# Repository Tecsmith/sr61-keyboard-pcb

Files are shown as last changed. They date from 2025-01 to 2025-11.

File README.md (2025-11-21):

# SR61 - MicroMod 60% Custom Keyboard PCB





***Featuring SparkFun's MicroMod Processor Boards***

---

> [PCBWay](https://pcbway.com) had gratefully sponsored the production of the first 5 RevA PCBs, and a partial assembly service.
>
> Official Sponsor - PCBWay (https://pcbway.com/)
>
> Thank you [PCBWay](https://pcbway.com/)!

Please follow the updates to this production process on the [changelog](CHANGELOG.md) page.

---

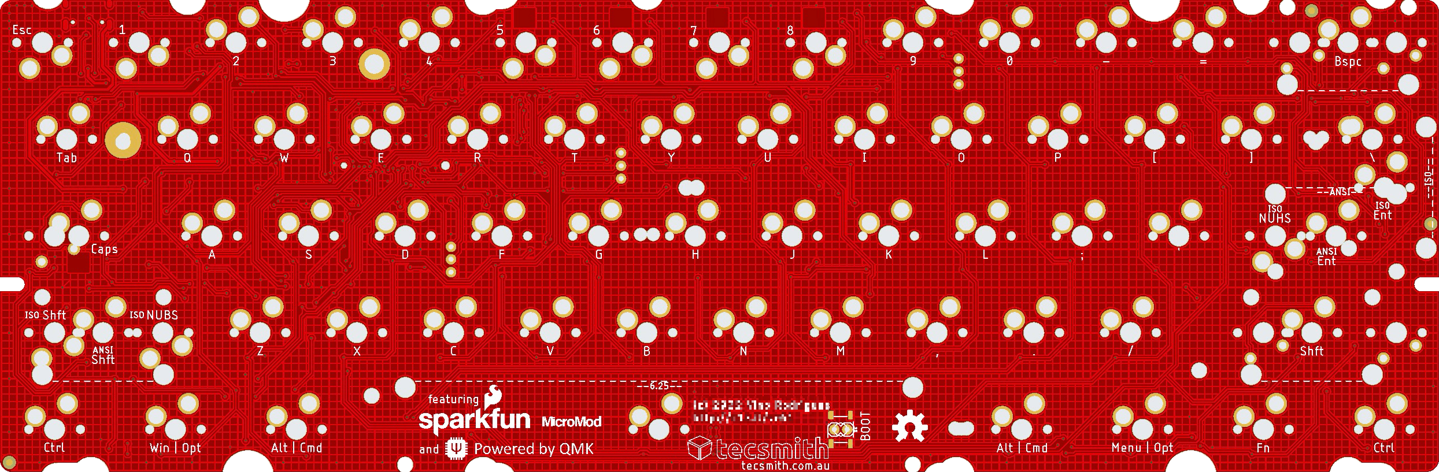
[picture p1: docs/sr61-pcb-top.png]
PCB Top View


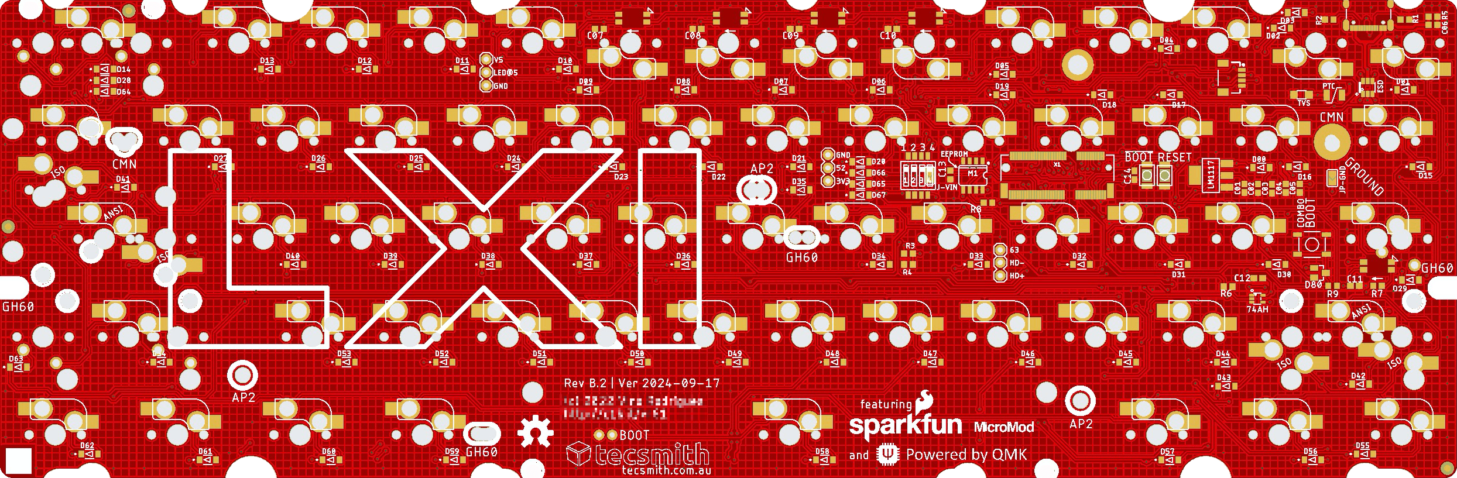
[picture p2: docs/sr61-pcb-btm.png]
PCB Bottom View


Published as Open Source, under a [ Creative Commons Share-alike 4.0 International](LICENSE.md).

### **Rev C** &nbsp; 

> ~~&#128077; **WORKING, OK TO BUILD**~~ &nbsp; 

* [PDF Schematic](docs/sr61-revC.pdf)
* [EAGLE PCB](EAGLE/sr61/sr61-revC.brd)
* [EAGLE Schematic](EAGLE/sr61/sr61-revC.sch)

* Notes:
    - Keymap Working on both STM32 and PR2040
    - *(Optional EEPROM not tested yet)*

### QMK code:

* https://github.com/Tecsmith/sr61-keyboard-qmk
* USB Identifier registered with [pid.codes](https://pid.codes/) = [`1209`/`7672`](https://pid.codes/1209/7672/)

### Layout

* [KLE JSON](./kle/sr61-micromod-poker.json)

*****

## Features

**SR61-MicroMod** - using SparkFun MicroMod STM32 or RP2040 M.2 module

### Core Design Elements

- 60% form factor
    - Design to be compatible with GH60/HK60 cases
    - Also compatible with Anne Pro 2 cases *(~~drop in~~ QMK replacement for existing AP2's or AP2 cases)* *[Removal of battery and minor case cut in the battery compartment required.]*
    - MicroMod positioned in case *"battery compartment"* space.

- QMK + VIA default f/w
    - Wired only *(no wireless)*
    - Default key-maps for Mac users

- User choice of microcontroller
    
    - [STM32 Processor](https://www.sparkfun.com/products/17713) 
        - ARM Cortex-M4, 168MHz, 1MB Flash, 192kB SRAM
        - https://github.com/Tecsmith/sr61-keyboard-qmk

    - [RP2040 Processor](https://www.sparkfun.com/products/17720) 
        - ARM Cortex-M0+, 133MHz, 128Mb Flash (16MB external), 264kB SRAM in six banks
        
- USB-C *(left side)*

    ... but also optional JST connector for [ai03 Unified C3 Daughterboard](https://github.com/ai03-2725/Unified-Daughterboard)

- ESD, Over Voltage and Over Current protection

    ... and cable shield noise filter

- Hot-swap, 5 pin switch slots

- PCB mounted stabs compatibility

- Dual ANSI / ISO layout support

- 61-Key (ANSI) / 62-Key (ISO) Layout [1.25, 1.25, 1.25, **6.25**, 1.25, 1.25, 1.25, 1.25] bottom row *(a.k.a. "Poker" / "POK3R" Layout)*

- Limited RGB LEDs *(SK6812 mini-E)*

    - RGB Caps Lock Indicator

    - North facing RGB's under the `5`, `6`, `7` & `8` keys for layer indicator

    - WS2812/SK6812 breakout for optional external LEDs

- Spare GPIO pins (`52` & `63`) breakout for expansion

   ... e.g., ~~add speaker~~

- Both `[Reset]` and `[Boot]` buttons *(as per MicroMod ref. design)*

    ... plus under space-bar Boot pins for bootload without disassembly *(press while inserting cable for bootloader function)*

---

Made with :heart: by Silvino R.

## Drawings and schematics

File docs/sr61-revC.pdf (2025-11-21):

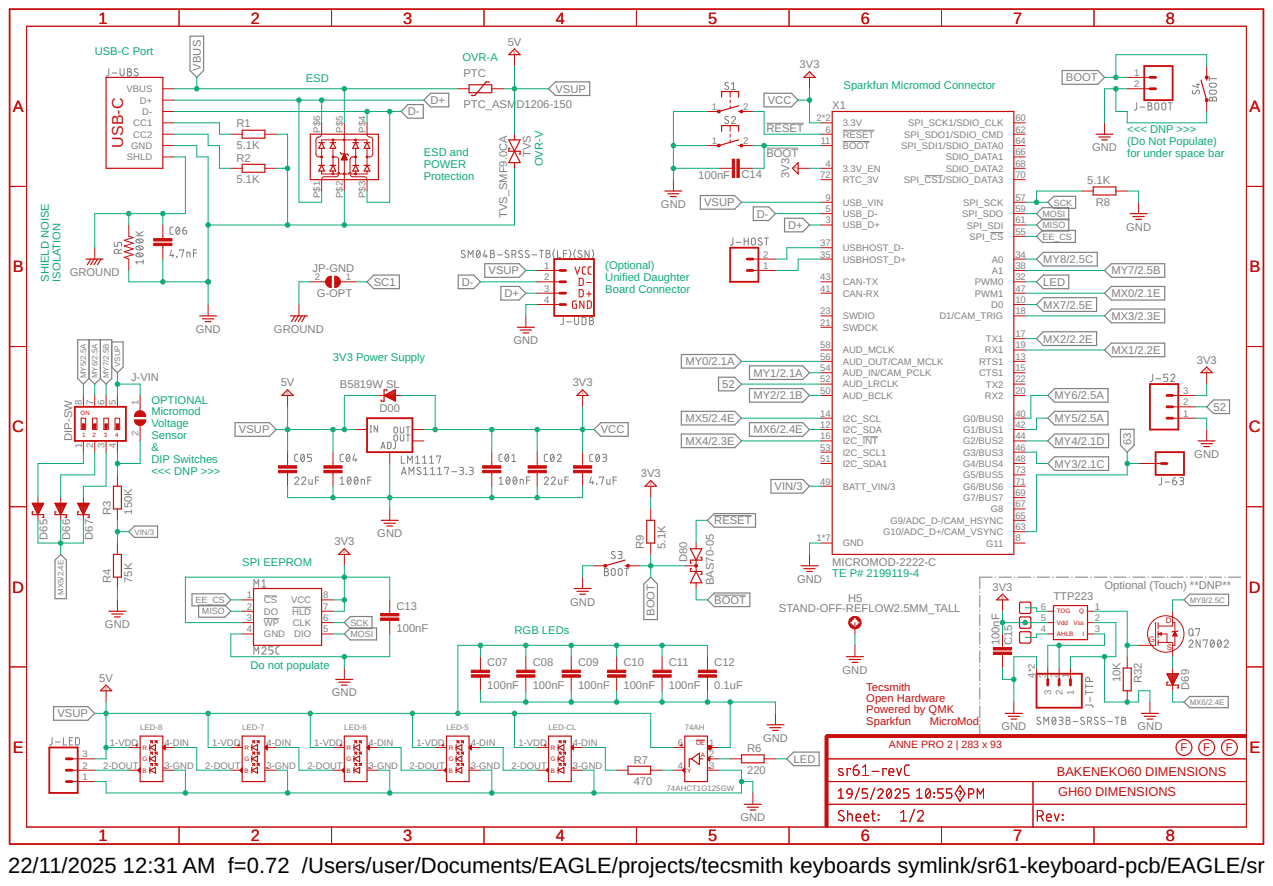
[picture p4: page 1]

<<< DNP >>>
(Do Not Populate)
GND
for under space bar

(Optional) Unified Daughter Board Connector

2 1 J-VIN
OPTIONAL Micromod Voltage Sensor &DIP Switches <<< DNP >>>

Open Hardware Sparkfun Powered by QMK

22/11/2025 12:31 AM f=0.72 /Users/user/Documents/EAGLE/projects/tecsmith keyboards symlink/sr61-keyboard-pcb/EAGLE/sr61/sr61-revC.sch (Sheet: 1/2)

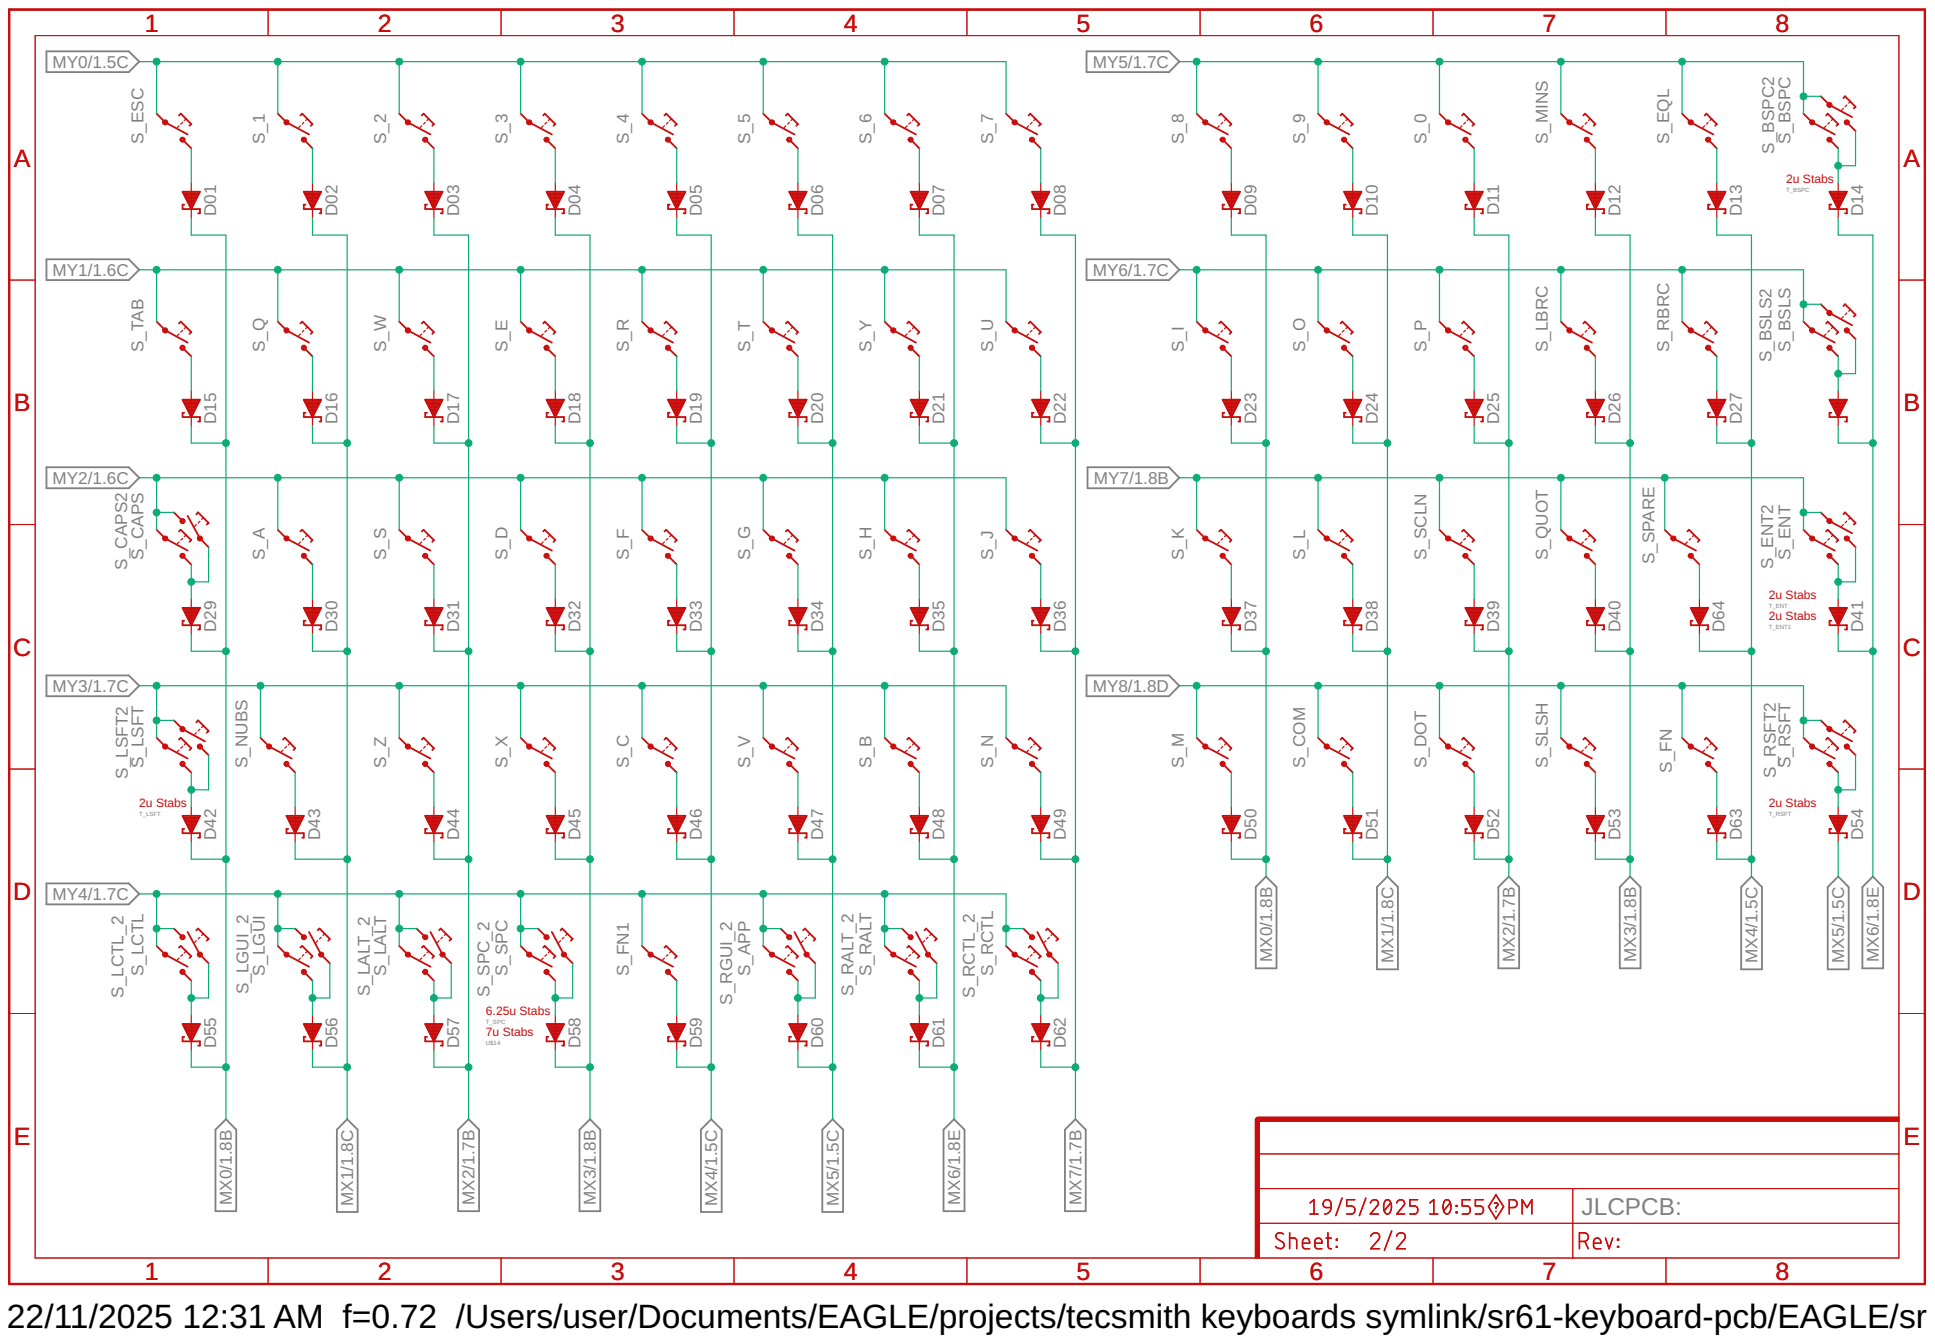
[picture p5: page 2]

22/11/2025 12:31 AM f=0.72 /Users/user/Documents/EAGLE/projects/tecsmith keyboards symlink/sr61-keyboard-pcb/EAGLE/sr61/sr61-revC.sch (Sheet: 2/2)

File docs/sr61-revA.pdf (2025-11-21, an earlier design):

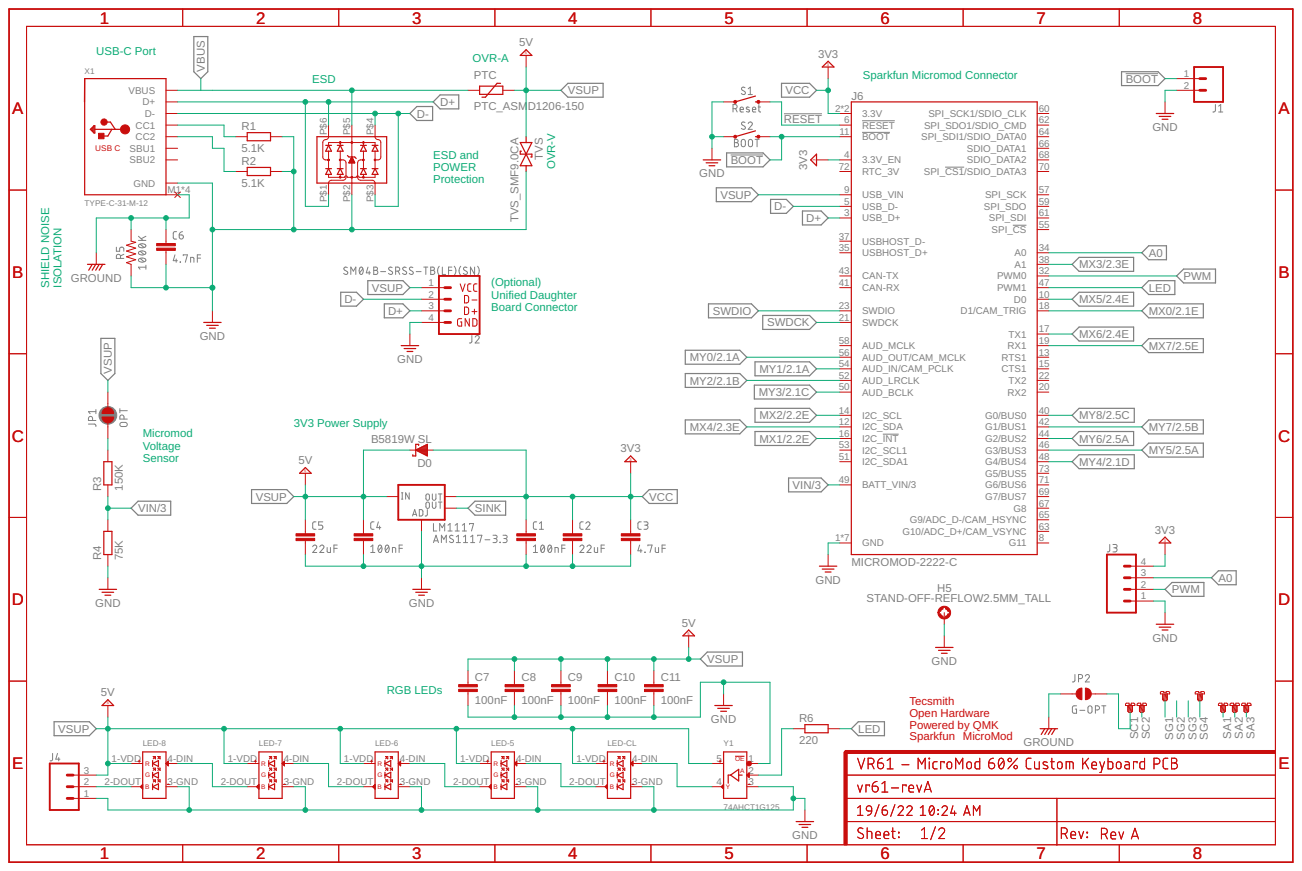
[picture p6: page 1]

(Optional)
Unified Daughter Board Connector

MX1/2.2E | I2C_SCL1 I2C_SDA1 BATT_VIN/3 | MY6/2.5A

Tecsmith
Open Hardware Sparkfun Powered by QMK

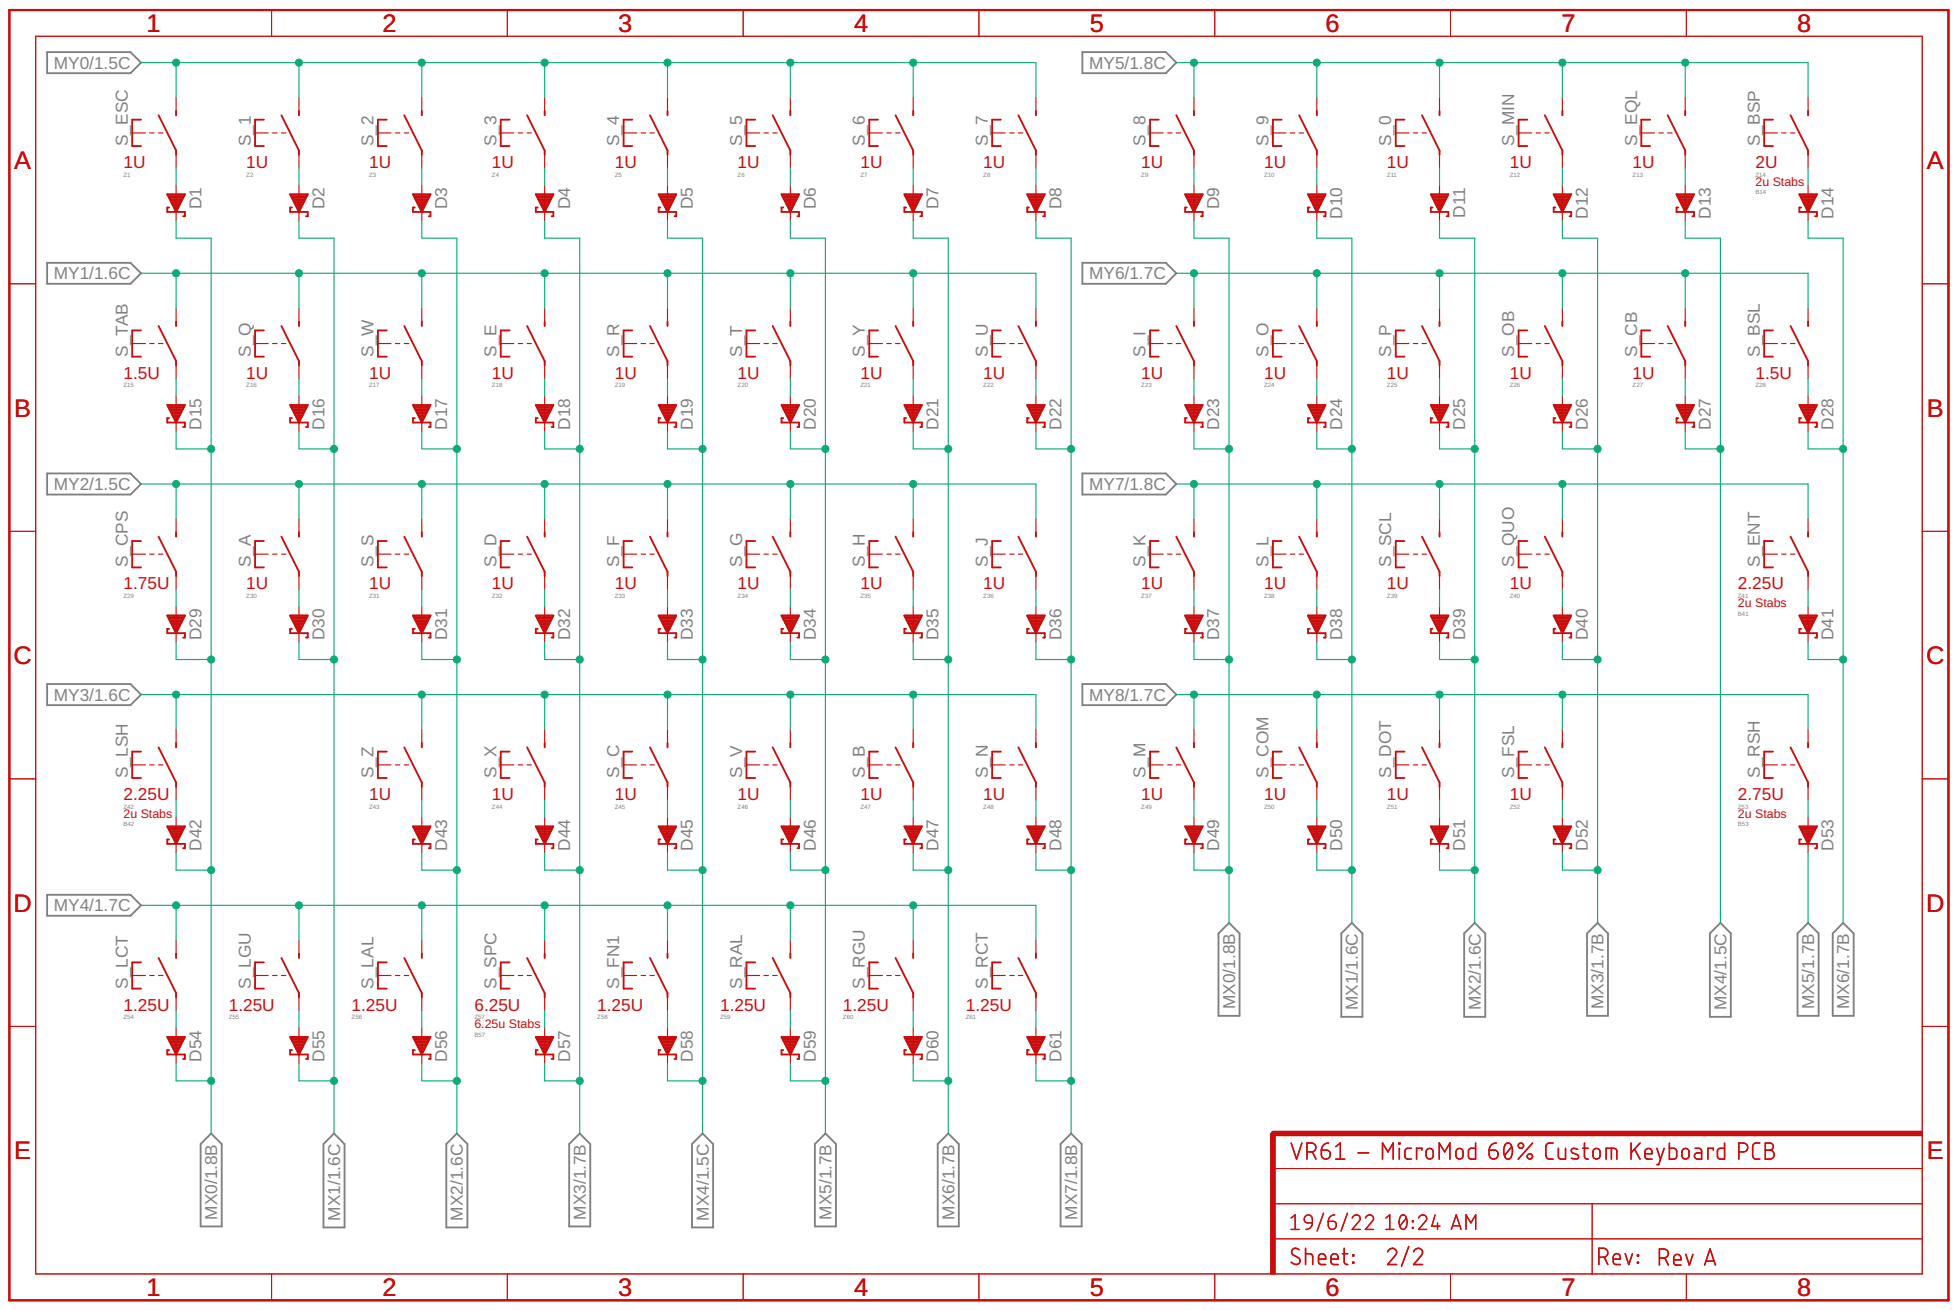
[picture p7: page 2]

S_ESC S_1 S_2 S_3 S_4 S_5 S_6 S_7 S_8 S_9 S_0 S_MIN S_EQL S_BSP D1 D2 D3 D4 D5 D6 D7 D8 D9 D10 D11 D12 D13 D14 S_TAB S_Q S_W S_E S_R S_T S_Y S_U S_I S_O S_P S_OB S_CB S_BSL D15 D16 D17 D18 D19 D20 D21 D22 D23 D24 D25 D26 D27 D28 S_CPS S_A S_S S_D S_F S_G S_H S_J S_K S_L S_SCL S_QUO S_ENT D29 D30 D31 D32 D33 D34 D35 D36 D37 D38 D39 D40 D41 S_LSH S_Z S_X S_C S_V S_B S_N S_M S_COM S_DOT S_FSL S_RSH D42 D43 D44 D45 D46 D47 D48 D49 D50 D51 D52 D53 S_LCT S_LGU S_LAL S_SPC S_FN1 S_RAL S_RGU S_RCT D54 D55 D56 D57 D58 D59 D60 D61 Z1 Z2 Z3 Z4 Z5 Z6 Z7 Z8 Z9 Z10 Z11 Z12 Z13 Z14 Z15 Z16 Z17 Z18 Z19 Z20 Z21 Z22 Z23 Z24 Z25 Z26 Z27 Z28 Z29 Z30 Z31 Z32 Z33 Z34 Z35 Z36 Z37 Z38 Z39 Z40 Z41 Z42 Z43 Z44 Z45 Z46 Z47 Z48 Z49 Z50 Z51 Z52 Z53 Z54 Z55 Z56 Z57 Z58 Z59 Z60 Z61 B14 B41 B42 B53 B57 MY0/1.5C MY1/1.6C MY2/1.5C MY3/1.6C MY4/1.7C MY5/1.8C MY6/1.7C MY7/1.8C MY8/1.7C MX5/1.7B MX5/1.7B MX6/1.7B MX6/1.7B MX7/1.8B MX0/1.8B MX0/1.8B MX1/1.6C MX1/1.6C MX2/1.6C MX2/1.6C MX3/1.7B MX3/1.7B MX4/1.5C MX4/1.5C ABCDE 1 2 3 4 5 6 7 8 ABCDE 1 2 3 4 5 6 7 8 ABCDE 1 2 3 4 5 6 7 8 ABCDE 1 2 3 4 5 6 7 8 1U 1U 1U 1U 1U 1U 1U 1U 1U 1U 1U 1U 1U 2U 1.5U 1U 1U 1U 1U 1U 1U 1U 1U 1U 1U 1U 1U 1.5U 1.75U 1U 1U 1U 1U 1U 1U 1U 1U 1U 1U 1U 2.25U 2.25U 1U 1U 1U 1U 1U 1U 1U 1U 1U 1U 2.75U 1.25U 1.25U 1.25U 6.25U 1.25U 1.25U 1.25U 1.25U 2u Stabs 2u Stabs 2u Stabs 2u Stabs 6.25u Stabs

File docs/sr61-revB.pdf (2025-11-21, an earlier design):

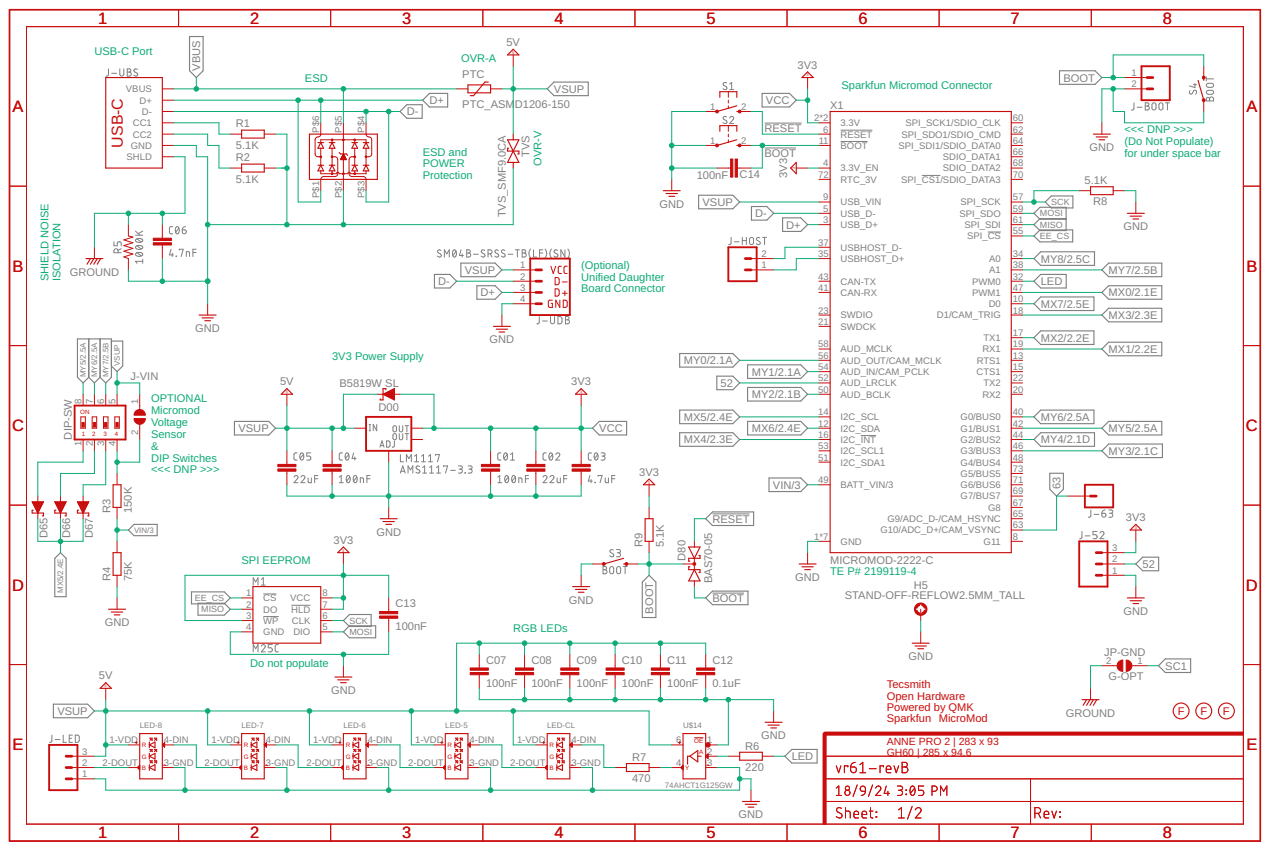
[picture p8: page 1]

<<< DNP >>>
(Do Not Populate)
GND
for under space bar

(Optional)
Unified Daughter Board Connector

Tecsmith
Open Hardware Sparkfun Powered by QMK

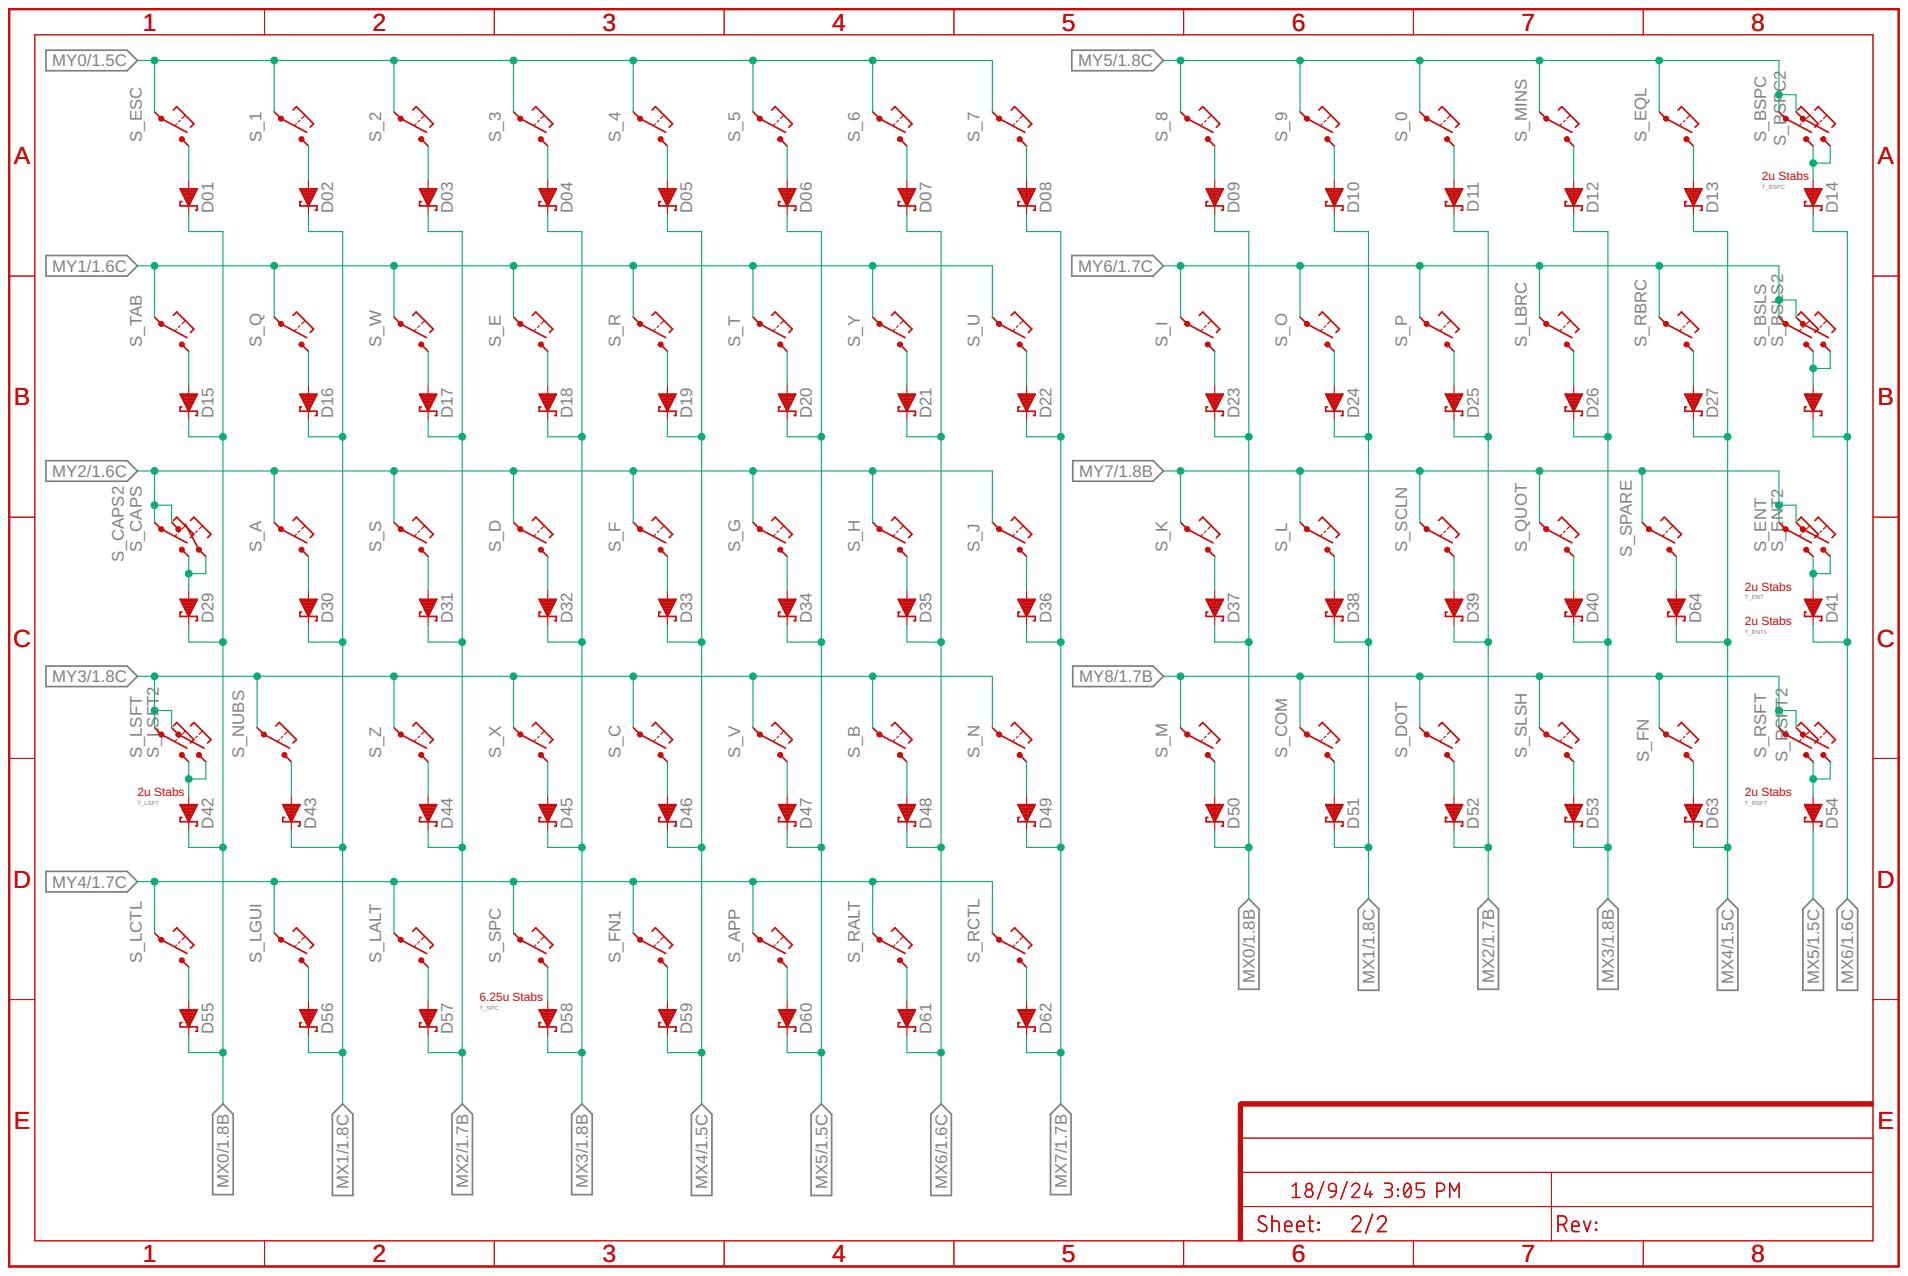
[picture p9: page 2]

S_ESC S_1 S_2 S_3 S_4 S_5 S_6 S_7 S_8 S_9 S_0 S_MINS S_EQL S_BSPC D01 D02 D03 D04 D05 D06 D07 D08 D09 D10 D11 D12 D13 D14 S_TAB S_Q S_W S_E S_R S_T S_Y S_U S_I S_O S_P S_LBRC S_RBRC S_BSLS D15 D16 D17 D18 D19 D20 D21 D22 D23 D24 D25 D26 D27 S_CAPS S_A S_S S_D S_F S_G S_H S_J S_K S_L S_SCLN S_QUOT S_ENT D29 D30 D31 D32 D33 D34 D35 D36 D37 D38 D39 D40 D41 S_LSFT S_Z S_X S_C S_V S_B S_N S_M S_COM S_DOT S_SLSH S_RSFT D42 D44 D45 D46 D47 D48 D49 D50 D51 D52 D53 D54 S_LCTL S_LGUI S_LALT S_SPC S_FN1 S_APP S_RALT S_RCTL D55 D56 D57 D58 D59 D60 D61 D62 T_BSPC T_ENT T_LSFT T_RSFT T_SPC D43 S_NUBS S_LSFT2 S_ENT2 S_BSLS2 T_ENT1 D63 S_RSFT2 S_FN S_BSPC2 S_SPARE D64 S_CAPS2 MY0/1.5C MY1/1.6C MY2/1.6C MY3/1.8C MY4/1.7C MY5/1.8C MY6/1.7C MY7/1.8B MY8/1.7B MX5/1.5C MX5/1.5C MX6/1.6C MX6/1.6C MX7/1.7B MX0/1.8B MX0/1.8B MX1/1.8C MX1/1.8C MX2/1.7B MX2/1.7B MX3/1.8B MX3/1.8B MX4/1.5C MX4/1.5C ABCDE 1 2 3 4 5 6 7 8 ABCDE 1 2 3 4 5 6 7 8 ABCDE 1 2 3 4 5 6 7 8 ABCDE 1 2 3 4 5 6 7 82u Stabs 2u Stabs 2u Stabs 2u Stabs 6.25u Stabs 2u Stabs

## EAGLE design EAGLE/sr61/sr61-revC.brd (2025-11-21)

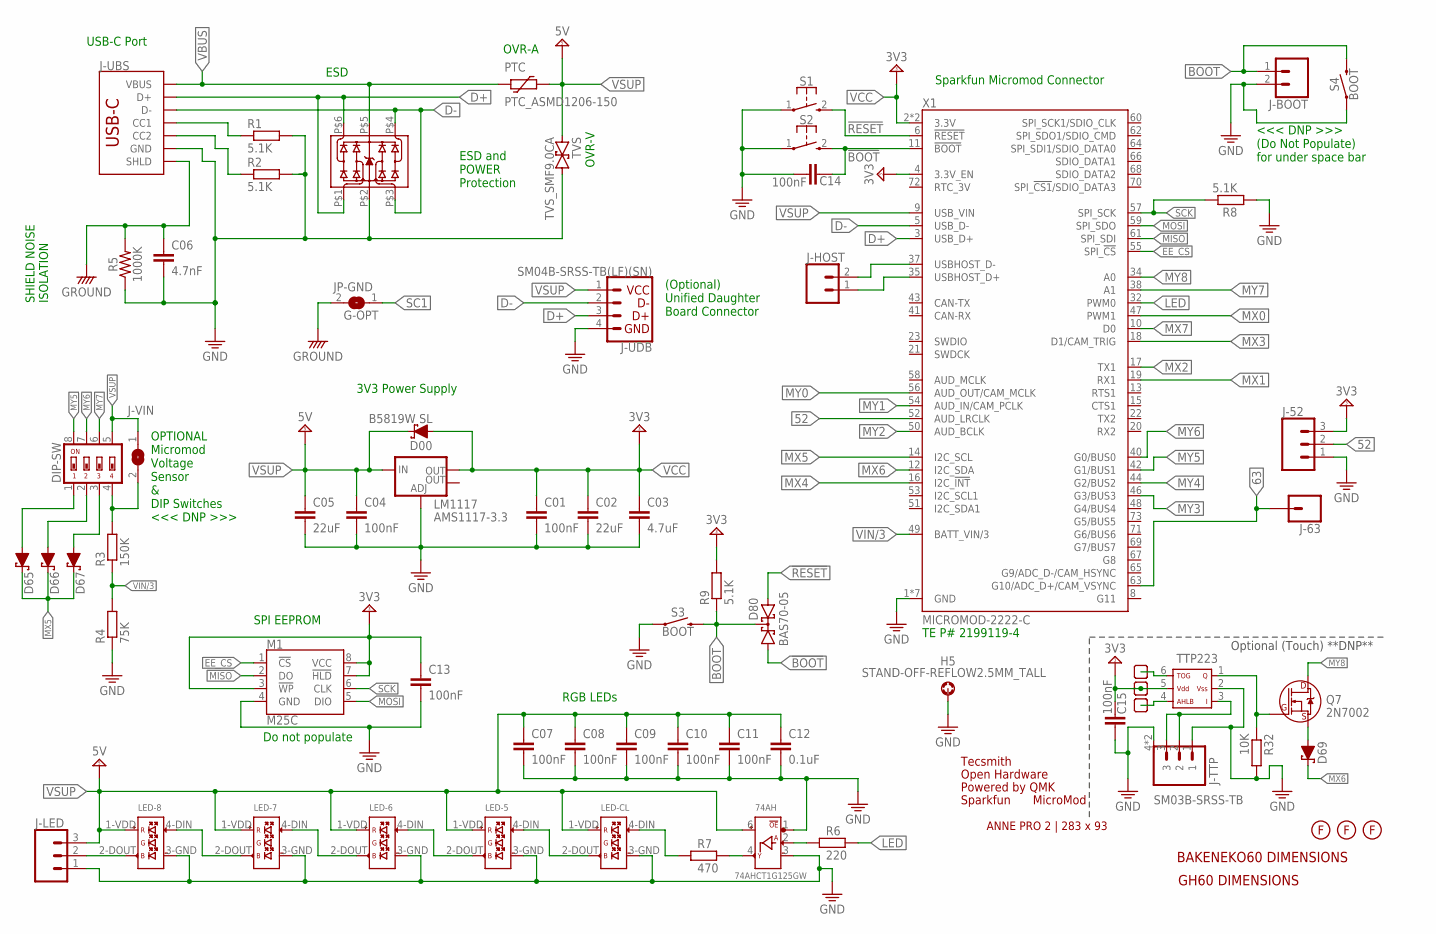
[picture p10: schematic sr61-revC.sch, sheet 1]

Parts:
74AH: 74AHCT1G125GW; SC-88A__TSSOP5__SOT353-1
C01, C04: 100nF; 0603
C02, C05: 22uF; 0603
C03: 4.7uF; 0603
C06: 4.7nF; 0603
C07, C08, C09, C10, C11, C13, C14, C15: 100nF; C0603
C12: 0.1uF; C0603
D00: B5819W SL; SOD-123
D65, D66, D67, D69: 1N5819WS; SOD-123
D80: BAS70-05; SOT23
DIP-SW: DIP004; DIP-1.27-004
ESD: ESD_SRV05-4; SOT-23-6L
FP_AP2: FOOTPRINT-AP2
H5: STAND-OFF-REFLOW2.5MM_TALL; STAND-OFF-REFLOW-M2.5
J-52: CONN_03; 1X03
J-63: CONN_01; 1X01
J-BOOT: CONN_02; 1X02
J-HOST: CONN_02; 1X02
J-LED: CONN_03; 1X03
J-TTP: SM03B-SRSS-TB; CONN_SM03B-SRSS-TB_JST
J-UBS: USB_C_2-LAYER; USB-C-16P
J-UDB: SM04B-SRSS-TB(LF)(SN); 1X04_1MM_RA
J-VIN: JUMPER-1X2; SOLDERJUMPER_ARROW_NOPASTE
JP-GND: G-OPT; SOLDERJUMPER_ARROW_NOPASTE
LED-5, LED-6, LED-7, LED-8: SK6812-E-REVERSE; SK6812-E-MILL
LED-CL: SK6812-E-REVERSE; SK6812-E-MILL
LM1117: AMS1117-3.3; SOT223
LOGO1: OSHW-LOGOL; OSHW-LOGO-L
M1: M25C; 8-SOIC
PTC: PTC_ASMD1206-150; SMD_PTC
Q7: 2N7002; SOT23-3
R1, R2, R8, R9: 5.1K; R0603
R3: 150K; R0603
R4: 75K; R0603
R5: 1000K; 0603
R6: 220; R0603
R7: 470; R0603
R32: 10K; R0603
S1, S2: MOMENTARY-SWITCH-SPST-1; SKRKAEE020
S3, S4: BOOT; TACTILE_SWITCH_SMD_5.2MM
TP1, TP2, TP3: TEST-POINT.3SQ; PAD.03X.03-SQ
TTP223: TTP223-BA6; TTP223B
TVS: TVS_SMF9.0CA; SOD123FL-BI
U$3: MICROMOD-LOGO
U$5: SPARKFUN_LOGO0.2; SFE_LOGO_NAME_FLAME_.2
U$6: QMK_LOGO
U$8: TECSMITH-LOGOLONG; TECSMITH-NAME
U$20, U$21, U$22: FIDUCIAL
U$24: FOOTPRINT-BAKENEKO60
U$27: FOOTPRINT-DIMS-GH60
X1: MICROMOD-2222-C; M.2-CONNECTOR-E

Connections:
52: J-52.2, X1.52 (AUD_LRCLK)
63: J-63.1, X1.63 (G10/ADC_D+/CAM_VSYNC)
!BOOT: C14.1, D80.1 (A1), S2.2 (3), X1.11 (!BOOT!)
!RESET: D80.2 (A2), S1.2 (3), X1.6 (!RESET!)
BOOT: D80.3 (C), J-BOOT.1, R9.1, S3.3 (2), S3.4 (2), S4.3 (2), S4.4 (2)
CC1: J-UBS.A5 (CC1), R1.1
CC2: J-UBS.B5 (CC2), R2.1
D+: ESD.P$1, ESD.P$6, J-UBS.A6 (D+), J-UBS.B6 (D+), J-UDB.3 (D+), X1.3 (USB_D+)
D-: ESD.P$3, ESD.P$4, J-UBS.A7 (D-), J-UBS.B7 (D-), J-UDB.2 (D-), X1.5 (USB_D-)
EE_CS: M1.1 (!CS), X1.55 (SPI_!CS!)
GND: 74AH.1 (!OE), 74AH.3 (3_GND), C01.2, C02.2, C03.2, C04.2, C05.2, C06.2, C07.2, C08.2, C09.2, C10.2, C11.2, C12.2, C13.2, C14.2, C15.2, ESD.P$2, H5.1, J-52.1, J-BOOT.2, J-LED.1, J-TTP.1, J-TTP.4 (M), J-TTP.5 (M), J-UBS.GND, J-UBS.GND2 (GND), J-UDB.4 (GND), LED-5.3-GND (3_GND), LED-6.3-GND (3_GND), LED-7.3-GND (3_GND), LED-8.3-GND (3_GND), LED-CL.3-GND (3_GND), LM1117.1 (ADJ), M1.4 (GND), R1.2, R2.2, R4.1, R5.1, R8.1, R32.2, S1.1, S2.1, S3.1, S3.2 (1), S4.1, S4.2 (1), TTP223.2, TVS.P$2 (2), X1.1 (GND), X1.7 (GND), X1.33 (GND), X1.36 (GND), X1.39 (GND), X1.45 (GND), X1.75 (GND)
GROUND: C06.1, J-UBS.SHLD1 (SHLD), J-UBS.SHLD2 (SHLD), J-UBS.SHLD3 (SHLD), J-UBS.SHLD4 (SHLD), J-UBS.SHLD5 (SHLD), J-UBS.SHLD6 (SHLD), J-UBS.SHLD7 (SHLD), J-UBS.SHLD8 (SHLD), JP-GND.2, R5.2
LED: R6.2, X1.32 (PWM0)
LED1ST: 74AH.2 (A_DIN), R6.1
MISO: M1.2 (DO), X1.61 (SPI_SDI)
MOSI: M1.5 (DIO), X1.59 (SPI_SDO)
MX0: X1.47 (PWM1); also elsewhere on the board
MX1: X1.19 (RX1); also elsewhere on the board
MX2: X1.17 (TX1); also elsewhere on the board
MX3: X1.18 (D1/CAM_TRIG); also elsewhere on the board
MX4: X1.16 (I2C_!INT!); also elsewhere on the board
MX5: D65.C, D66.C, D67.C, X1.14 (I2C_SCL); also elsewhere on the board
MX6: D69.C, X1.12 (I2C_SDA); also elsewhere on the board
MX7: X1.10 (D0); also elsewhere on the board
MY0: X1.56 (AUD_OUT/CAM_MCLK); also elsewhere on the board
MY1: X1.54 (AUD_IN/CAM_PCLK); also elsewhere on the board
MY2: X1.50 (AUD_BCLK); also elsewhere on the board
MY3: X1.46 (G3/BUS3); also elsewhere on the board
MY4: X1.44 (G2/BUS2); also elsewhere on the board
MY5: DIP-SW.8, X1.42 (G1/BUS1); also elsewhere on the board
MY6: DIP-SW.7, X1.40 (G0/BUS0); also elsewhere on the board
MY7: DIP-SW.6, X1.38 (A1); also elsewhere on the board
MY8: Q7.3 (D), X1.34 (A0); also elsewhere on the board
unnamed: LED-5.4-DIN (4_DIN), LED-CL.2-DOUT (2_DOUT)
unnamed: LED-5.2-DOUT (2_DOUT), LED-6.4-DIN (4_DIN)
unnamed: LED-6.2-DOUT (2_DOUT), LED-7.4-DIN (4_DIN)
unnamed: LED-7.2-DOUT (2_DOUT), LED-8.4-DIN (4_DIN)
unnamed: 74AH.4 (Y_DOUT), R7.2
unnamed: LED-CL.4-DIN (4_DIN), R7.1
unnamed: TP1.1, TTP223.6
unnamed: J-LED.2, LED-8.2-DOUT (2_DOUT)
unnamed: D65.A, DIP-SW.1
unnamed: DIP-SW.4, J-VIN.2, R3.2
unnamed: D66.A, DIP-SW.2
unnamed: D67.A, DIP-SW.3
unnamed: TP3.1, TTP223.4
unnamed: D69.A, Q7.2 (S)
unnamed: Q7.1 (G), R32.1, TTP223.1
unnamed: J-TTP.2, J-TTP.3, TTP223.3
SC1: JP-GND.1
SCK: M1.6 (CLK), R8.2, X1.57 (SPI_SCK)
USBHOST_D+: J-HOST.1, X1.35 (USBHOST_D+)
USBHOST_D-: J-HOST.2, X1.37 (USBHOST_D-)
VBUS: ESD.P$5, J-UBS.VBUS1 (VBUS), J-UBS.VBUS2 (VBUS), PTC.P$1 (1)
VCC: C01.1, C02.1, C03.1, C13.1, C15.1, D00.A, J-52.3, LM1117.2 (OUT), M1.3 (!WP), M1.7 (!HLD), M1.8 (VCC), R9.2, TP2.1, TTP223.5, X1.2 (3.3V), X1.4 (3.3V_EN), X1.74 (3.3V)
VIN/3: R3.1, R4.2, X1.49 (BATT_VIN/3)
VSUP: 74AH.6 (5_VCC), C04.1, C05.1, C07.1, C08.1, C09.1, C10.1, C11.1, C12.1, D00.C, DIP-SW.5, J-LED.3, J-UDB.1 (VCC), J-VIN.1, LED-5.1-VDD (1_VDD), LED-6.1-VDD (1_VDD), LED-7.1-VDD (1_VDD), LED-8.1-VDD (1_VDD), LED-CL.1-VDD (1_VDD), LM1117.3 (IN), PTC.P$2 (2), TVS.P$1 (1), X1.9 (USB_VIN)

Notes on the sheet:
ESD
OVR-A
OVR-V
USB-C Port
ESD and POWER Protection
OPTIONAL Micromod Voltage Sensor & DIP Switches <<< DNP >>>
(Optional) Unified Daughter Board Connector
Sparkfun Micromod Connector
3V3 Power Supply
RGB LEDs
SHIELD NOISE ISOLATION
SPI EEPROM
TE P# 2199119-4
<<< DNP >>> (Do Not Populate) for under space bar
Do not populate
Optional (Touch) **DNP**

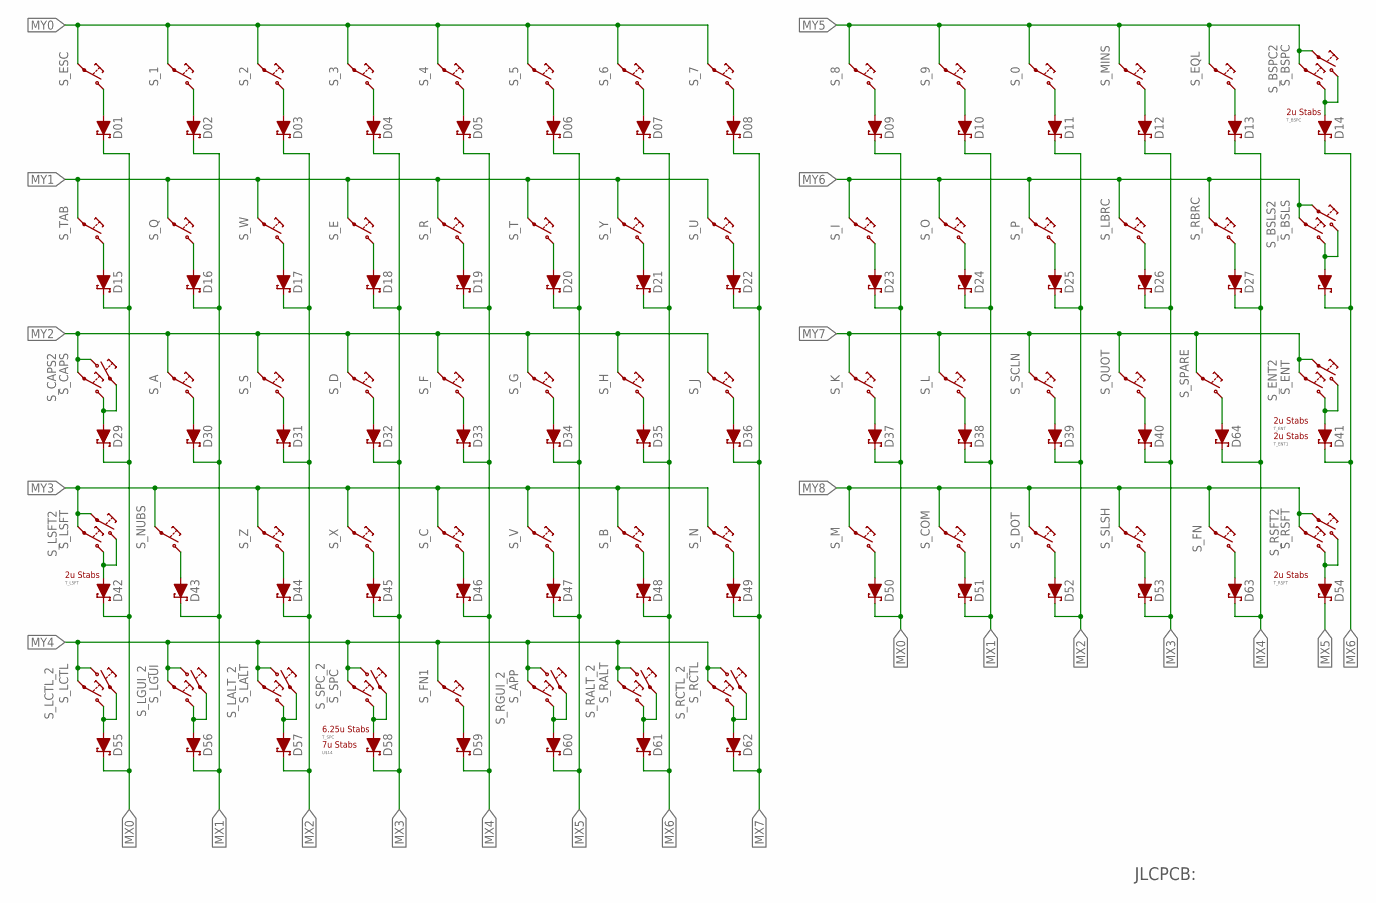
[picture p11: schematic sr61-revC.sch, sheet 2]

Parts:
D01, D02, D03, D04, D05, D06, D07, D08, D09, D10, D11, D12, D13, D14, D15, D16, D17, D18, D19, D20, D21, D22, D23, D24, D25, D26, D27, D28, D29, D30, D31, D32, D33, D34, D35, D36, D37, D38, D39, D40, D41, D42, D43, D44, D45, D46, D47, D48, D49, D50, D51, D52, D53, D54, D55, D56, D57, D58, D59, D60, D61, D62, D63, D64: 1N5819WS; SOD-123
S_0, S_1, S_2, S_3, S_4, S_5, S_6, S_7, S_8, S_9: MX-5-PIN-HOTSWAP-VIA
S_A: MX-5-PIN-HOTSWAP-VIA
S_APP: MX-5-PIN-HOTSWAP-VIA
S_B: MX-5-PIN-HOTSWAP-VIA
S_BSLS: MX-5-PIN-HOTSWAP-VIA
S_BSLS2: MX-5-PIN-HOTSWAP-VIANO-SILK; MX-5-PIN-HOTSWAP-VIA-NS
S_BSPC: MX-5-PIN-HOTSWAP-VIA
S_BSPC2: MX-5-PIN-HOTSWAP-VIANO-SILK; MX-5-PIN-HOTSWAP-VIA-NS
S_C: MX-5-PIN-HOTSWAP-VIA
S_CAPS: MX-5-PIN-HOTSWAP-VIA
S_CAPS2: MX-5-PIN-MILMAX-3305-XNO-SILK; MX-5-PIN-MILMAX-3305-X-NS
S_COM: MX-5-PIN-HOTSWAP-VIA
S_D: MX-5-PIN-HOTSWAP-VIA
S_DOT: MX-5-PIN-HOTSWAP-VIA
S_E: MX-5-PIN-HOTSWAP-VIA
S_ENT: MX-5-PIN-HOTSWAP-VIA
S_ENT2: MX-5-PIN-HOTSWAP-VIANO-SILK; MX-5-PIN-HOTSWAP-VIA-NS
S_EQL: MX-5-PIN-HOTSWAP-VIA
S_ESC: MX-5-PIN-HOTSWAP-VIA
S_F: MX-5-PIN-HOTSWAP-VIA
S_FN: MX-5-PIN-HOTSWAP-VIANO-SILK; MX-5-PIN-HOTSWAP-VIA-NS
S_FN1: MX-5-PIN-HOTSWAP-VIA
S_G: MX-5-PIN-HOTSWAP-VIA
S_H: MX-5-PIN-HOTSWAP-VIA
S_I: MX-5-PIN-HOTSWAP-VIA
S_J: MX-5-PIN-HOTSWAP-VIA
S_K: MX-5-PIN-HOTSWAP-VIA
S_L: MX-5-PIN-HOTSWAP-VIA
S_LALT: MX-5-PIN-HOTSWAP-VIA
S_LALT_2: MX-5-PIN-HOTSWAP-VIANO-SILK; MX-5-PIN-HOTSWAP-VIA-NS
S_LBRC: MX-5-PIN-HOTSWAP-VIA
S_LCTL: MX-5-PIN-HOTSWAP-VIA
S_LCTL_2: MX-5-PIN-HOTSWAP-VIANO-SILK; MX-5-PIN-HOTSWAP-VIA-NS
S_LGUI: MX-5-PIN-HOTSWAP-VIA
S_LGUI_2: MX-5-PIN-HOTSWAP-VIANO-SILK; MX-5-PIN-HOTSWAP-VIA-NS
S_LSFT: MX-5-PIN-HOTSWAP-VIA
S_LSFT2: MX-5-PIN-HOTSWAP-VIANO-SILK; MX-5-PIN-HOTSWAP-VIA-NS
S_M: MX-5-PIN-HOTSWAP-VIA
S_MINS: MX-5-PIN-HOTSWAP-VIA
S_N: MX-5-PIN-HOTSWAP-VIA
S_NUBS: MX-5-PIN-HOTSWAP-VIANO-SILK; MX-5-PIN-HOTSWAP-VIA-NS
S_O: MX-5-PIN-HOTSWAP-VIA
S_P: MX-5-PIN-HOTSWAP-VIA
S_Q: MX-5-PIN-HOTSWAP-VIA
S_QUOT: MX-5-PIN-HOTSWAP-VIA
S_R: MX-5-PIN-HOTSWAP-VIA
S_RALT: MX-5-PIN-HOTSWAP-VIA
S_RALT_2: MX-5-PIN-HOTSWAP-VIANO-SILK; MX-5-PIN-HOTSWAP-VIA-NS
S_RBRC: MX-5-PIN-HOTSWAP-VIA
S_RCTL: MX-5-PIN-HOTSWAP-VIA
S_RCTL_2: MX-5-PIN-HOTSWAP-VIANO-SILK; MX-5-PIN-HOTSWAP-VIA-NS
S_RGUI_2: MX-5-PIN-HOTSWAP-VIANO-SILK; MX-5-PIN-HOTSWAP-VIA-NS
S_RSFT: MX-5-PIN-HOTSWAP-VIA
S_RSFT2: MX-5-PIN-HOTSWAP-VIANO-SILK; MX-5-PIN-HOTSWAP-VIA-NS
S_S: MX-5-PIN-HOTSWAP-VIA
S_SCLN: MX-5-PIN-HOTSWAP-VIA
S_SLSH: MX-5-PIN-HOTSWAP-VIA
S_SPARE: MX-5-PIN-HOTSWAP-VIANO-SILK; MX-5-PIN-HOTSWAP-VIA-NS
S_SPC: MX-5-PIN-HOTSWAP-VIA
S_SPC_2: MX-5-PIN-HOTSWAP-VIANO-SILK; MX-5-PIN-HOTSWAP-VIA-NS
S_T: MX-5-PIN-HOTSWAP-VIA
S_TAB: MX-5-PIN-HOTSWAP-VIA
S_U: MX-5-PIN-HOTSWAP-VIA
S_V: MX-5-PIN-HOTSWAP-VIA
S_W: MX-5-PIN-HOTSWAP-VIA
S_X: MX-5-PIN-HOTSWAP-VIA
S_Y: MX-5-PIN-HOTSWAP-VIA
S_Z: MX-5-PIN-HOTSWAP-VIA
T_BSPC: MX-STABS-200U
T_ENT, T_ENT1: MX-STABS-200U
T_LSFT: MX-STABS-200U
T_RSFT: MX-STABS-200U
T_SPC: MX-STABS-625U
U$14: MX-STABS-700U
U$26: ?; JLC_ORDER_NUMBER_QR_5X5

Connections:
MX0: D01.C, D09.C, D15.C, D23.C, D29.C, D37.C, D42.C, D50.C, D55.C; also elsewhere on the board
MX1: D02.C, D10.C, D16.C, D24.C, D30.C, D38.C, D43.C, D51.C, D56.C; also elsewhere on the board
MX2: D03.C, D11.C, D17.C, D25.C, D31.C, D39.C, D44.C, D52.C, D57.C; also elsewhere on the board
MX3: D04.C, D12.C, D18.C, D26.C, D32.C, D40.C, D45.C, D53.C, D58.C; also elsewhere on the board
MX4: D05.C, D13.C, D19.C, D27.C, D33.C, D46.C, D59.C, D63.C, D64.C; also elsewhere on the board
MX5: D06.C, D20.C, D34.C, D47.C, D54.C, D60.C; also elsewhere on the board
MX6: D07.C, D14.C, D21.C, D28.C, D35.C, D41.C, D48.C, D61.C; also elsewhere on the board
MX7: D08.C, D22.C, D36.C, D49.C, D62.C; also elsewhere on the board
MY0: S_1.2@1 (1), S_1.2@2 (1), S_2.2@1 (1), S_2.2@2 (1), S_3.2@1 (1), S_3.2@2 (1), S_4.2@1 (1), S_4.2@2 (1), S_5.2@1 (1), S_5.2@2 (1), S_6.2@1 (1), S_6.2@2 (1), S_7.2@1 (1), S_7.2@2 (1), S_ESC.2@1 (1), S_ESC.2@2 (1); also elsewhere on the board
MY1: S_E.2@1 (1), S_E.2@2 (1), S_Q.2@1 (1), S_Q.2@2 (1), S_R.2@1 (1), S_R.2@2 (1), S_T.2@1 (1), S_T.2@2 (1), S_TAB.2@1 (1), S_TAB.2@2 (1), S_U.2@1 (1), S_U.2@2 (1), S_W.2@1 (1), S_W.2@2 (1), S_Y.2@1 (1), S_Y.2@2 (1); also elsewhere on the board
MY2: S_A.2@1 (1), S_A.2@2 (1), S_CAPS.2@1 (1), S_CAPS.2@2 (1), S_CAPS2.1 (2), S_D.2@1 (1), S_D.2@2 (1), S_F.2@1 (1), S_F.2@2 (1), S_G.2@1 (1), S_G.2@2 (1), S_H.2@1 (1), S_H.2@2 (1), S_J.2@1 (1), S_J.2@2 (1), S_S.2@1 (1), S_S.2@2 (1); also elsewhere on the board
MY3: S_B.2@1 (1), S_B.2@2 (1), S_C.2@1 (1), S_C.2@2 (1), S_LSFT.2@1 (1), S_LSFT.2@2 (1), S_LSFT2.2@1 (1), S_LSFT2.2@2 (1), S_N.2@1 (1), S_N.2@2 (1), S_NUBS.2@1 (1), S_NUBS.2@2 (1), S_V.2@1 (1), S_V.2@2 (1), S_X.2@1 (1), S_X.2@2 (1), S_Z.2@1 (1), S_Z.2@2 (1); also elsewhere on the board
MY4: S_APP.2@1 (1), S_APP.2@2 (1), S_FN1.2@1 (1), S_FN1.2@2 (1), S_LALT.2@1 (1), S_LALT.2@2 (1), S_LALT_2.1@1 (2), S_LALT_2.1@2 (2), S_LCTL.2@1 (1), S_LCTL.2@2 (1), S_LCTL_2.1@1 (2), S_LCTL_2.1@2 (2), S_LGUI.2@1 (1), S_LGUI.2@2 (1), S_LGUI_2.1@1 (2), S_LGUI_2.1@2 (2), S_RALT.2@1 (1), S_RALT.2@2 (1), S_RALT_2.1@1 (2), S_RALT_2.1@2 (2), S_RCTL.2@1 (1), S_RCTL.2@2 (1), S_RCTL_2.1@1 (2), S_RCTL_2.1@2 (2), S_RGUI_2.1@1 (2), S_RGUI_2.1@2 (2), S_SPC.2@1 (1), S_SPC.2@2 (1), S_SPC_2.1@1 (2), S_SPC_2.1@2 (2); also elsewhere on the board
MY5: S_0.2@1 (1), S_0.2@2 (1), S_8.2@1 (1), S_8.2@2 (1), S_9.2@1 (1), S_9.2@2 (1), S_BSPC.2@1 (1), S_BSPC.2@2 (1), S_BSPC2.2@1 (1), S_BSPC2.2@2 (1), S_EQL.2@1 (1), S_EQL.2@2 (1), S_MINS.2@1 (1), S_MINS.2@2 (1); also elsewhere on the board
MY6: S_BSLS.2@1 (1), S_BSLS.2@2 (1), S_BSLS2.2@1 (1), S_BSLS2.2@2 (1), S_I.2@1 (1), S_I.2@2 (1), S_LBRC.2@1 (1), S_LBRC.2@2 (1), S_O.2@1 (1), S_O.2@2 (1), S_P.2@1 (1), S_P.2@2 (1), S_RBRC.2@1 (1), S_RBRC.2@2 (1); also elsewhere on the board
MY7: S_ENT.2@1 (1), S_ENT.2@2 (1), S_ENT2.2@1 (1), S_ENT2.2@2 (1), S_K.2@1 (1), S_K.2@2 (1), S_L.2@1 (1), S_L.2@2 (1), S_QUOT.2@1 (1), S_QUOT.2@2 (1), S_SCLN.2@1 (1), S_SCLN.2@2 (1), S_SPARE.2@1 (1), S_SPARE.2@2 (1); also elsewhere on the board
MY8: S_COM.2@1 (1), S_COM.2@2 (1), S_DOT.2@1 (1), S_DOT.2@2 (1), S_FN.2@1 (1), S_FN.2@2 (1), S_M.2@1 (1), S_M.2@2 (1), S_RSFT.2@1 (1), S_RSFT.2@2 (1), S_RSFT2.2@1 (1), S_RSFT2.2@2 (1), S_SLSH.2@1 (1), S_SLSH.2@2 (1); also elsewhere on the board
unnamed: D01.A, S_ESC.1@1 (2), S_ESC.1@2 (2)
unnamed: D02.A, S_1.1@1 (2), S_1.1@2 (2)
unnamed: D03.A, S_2.1@1 (2), S_2.1@2 (2)
unnamed: D04.A, S_3.1@1 (2), S_3.1@2 (2)
unnamed: D05.A, S_4.1@1 (2), S_4.1@2 (2)
unnamed: D06.A, S_5.1@1 (2), S_5.1@2 (2)
unnamed: D07.A, S_6.1@1 (2), S_6.1@2 (2)
unnamed: D08.A, S_7.1@1 (2), S_7.1@2 (2)
unnamed: D09.A, S_8.1@1 (2), S_8.1@2 (2)
unnamed: D10.A, S_9.1@1 (2), S_9.1@2 (2)
unnamed: D11.A, S_0.1@1 (2), S_0.1@2 (2)
unnamed: D12.A, S_MINS.1@1 (2), S_MINS.1@2 (2)
unnamed: D13.A, S_EQL.1@1 (2), S_EQL.1@2 (2)
unnamed: D14.A, S_BSPC.1@1 (2), S_BSPC.1@2 (2), S_BSPC2.1@1 (2), S_BSPC2.1@2 (2)
unnamed: D15.A, S_TAB.1@1 (2), S_TAB.1@2 (2)
unnamed: D16.A, S_Q.1@1 (2), S_Q.1@2 (2)
unnamed: D17.A, S_W.1@1 (2), S_W.1@2 (2)
unnamed: D18.A, S_E.1@1 (2), S_E.1@2 (2)
unnamed: D19.A, S_R.1@1 (2), S_R.1@2 (2)
unnamed: D20.A, S_T.1@1 (2), S_T.1@2 (2)
unnamed: D21.A, S_Y.1@1 (2), S_Y.1@2 (2)
unnamed: D22.A, S_U.1@1 (2), S_U.1@2 (2)
unnamed: D23.A, S_I.1@1 (2), S_I.1@2 (2)
unnamed: D24.A, S_O.1@1 (2), S_O.1@2 (2)
unnamed: D25.A, S_P.1@1 (2), S_P.1@2 (2)
unnamed: D26.A, S_LBRC.1@1 (2), S_LBRC.1@2 (2)
unnamed: D27.A, S_RBRC.1@1 (2), S_RBRC.1@2 (2)
unnamed: D28.A, S_BSLS.1@1 (2), S_BSLS.1@2 (2), S_BSLS2.1@1 (2), S_BSLS2.1@2 (2)
unnamed: D30.A, S_A.1@1 (2), S_A.1@2 (2)
unnamed: D31.A, S_S.1@1 (2), S_S.1@2 (2)
unnamed: D32.A, S_D.1@1 (2), S_D.1@2 (2)
unnamed: D33.A, S_F.1@1 (2), S_F.1@2 (2)
unnamed: D34.A, S_G.1@1 (2), S_G.1@2 (2)
unnamed: D35.A, S_H.1@1 (2), S_H.1@2 (2)
unnamed: D36.A, S_J.1@1 (2), S_J.1@2 (2)
unnamed: D37.A, S_K.1@1 (2), S_K.1@2 (2)
unnamed: D38.A, S_L.1@1 (2), S_L.1@2 (2)
unnamed: D39.A, S_SCLN.1@1 (2), S_SCLN.1@2 (2)
unnamed: D40.A, S_QUOT.1@1 (2), S_QUOT.1@2 (2)
unnamed: D41.A, S_ENT.1@1 (2), S_ENT.1@2 (2), S_ENT2.1@1 (2), S_ENT2.1@2 (2)
unnamed: D42.A, S_LSFT.1@1 (2), S_LSFT.1@2 (2), S_LSFT2.1@1 (2), S_LSFT2.1@2 (2)
unnamed: D44.A, S_Z.1@1 (2), S_Z.1@2 (2)
unnamed: D45.A, S_X.1@1 (2), S_X.1@2 (2)
unnamed: D46.A, S_C.1@1 (2), S_C.1@2 (2)
unnamed: D47.A, S_V.1@1 (2), S_V.1@2 (2)
unnamed: D48.A, S_B.1@1 (2), S_B.1@2 (2)
unnamed: D49.A, S_N.1@1 (2), S_N.1@2 (2)
unnamed: D50.A, S_M.1@1 (2), S_M.1@2 (2)
unnamed: D51.A, S_COM.1@1 (2), S_COM.1@2 (2)
unnamed: D52.A, S_DOT.1@1 (2), S_DOT.1@2 (2)
unnamed: D53.A, S_SLSH.1@1 (2), S_SLSH.1@2 (2)
unnamed: D54.A, S_RSFT.1@1 (2), S_RSFT.1@2 (2), S_RSFT2.1@1 (2), S_RSFT2.1@2 (2)
unnamed: D55.A, S_LCTL.1@1 (2), S_LCTL.1@2 (2), S_LCTL_2.2@1 (1), S_LCTL_2.2@2 (1)
unnamed: D56.A, S_LGUI.1@1 (2), S_LGUI.1@2 (2), S_LGUI_2.2@1 (1), S_LGUI_2.2@2 (1)
unnamed: D57.A, S_LALT.1@1 (2), S_LALT.1@2 (2), S_LALT_2.2@1 (1), S_LALT_2.2@2 (1)
unnamed: D58.A, S_SPC.1@1 (2), S_SPC.1@2 (2), S_SPC_2.2@1 (1), S_SPC_2.2@2 (1)
unnamed: D59.A, S_FN1.1@1 (2), S_FN1.1@2 (2)
unnamed: D60.A, S_APP.1@1 (2), S_APP.1@2 (2), S_RGUI_2.2@1 (1), S_RGUI_2.2@2 (1)
unnamed: D61.A, S_RALT.1@1 (2), S_RALT.1@2 (2), S_RALT_2.2@1 (1), S_RALT_2.2@2 (1)
unnamed: D62.A, S_RCTL.1@1 (2), S_RCTL.1@2 (2), S_RCTL_2.2@1 (1), S_RCTL_2.2@2 (1)
unnamed: D29.A, S_CAPS.1@1 (2), S_CAPS.1@2 (2), S_CAPS2.2 (1)
unnamed: D43.A, S_NUBS.1@1 (2), S_NUBS.1@2 (2)
unnamed: D64.A, S_SPARE.1@1 (2), S_SPARE.1@2 (2)
unnamed: D63.A, S_FN.1@1 (2), S_FN.1@2 (2)

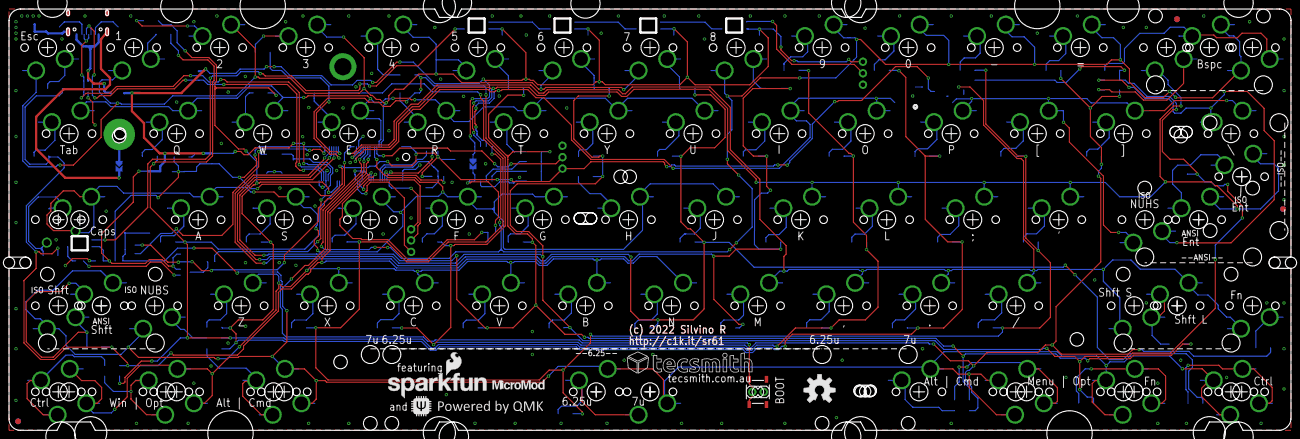
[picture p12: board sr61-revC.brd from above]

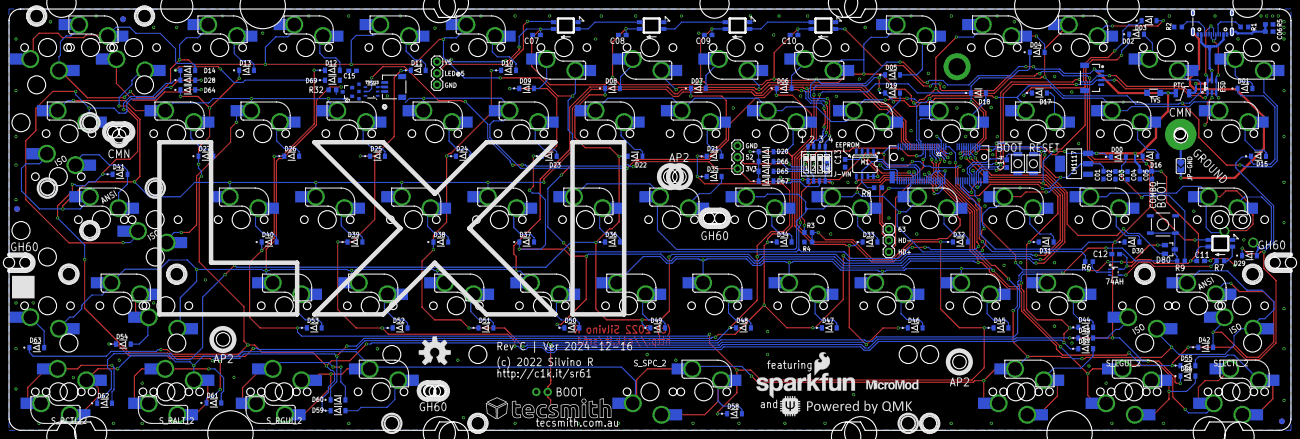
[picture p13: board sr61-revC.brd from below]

Board: 2 copper layers, 283.8 x 93.2 mm, 229 parts (126 on the bottom side), 120 nets.

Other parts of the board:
LOGO2: OSHW-LOGOL; OSHW-LOGO-L
U$7: TECSMITH-LOGOLONG; TECSMITH-NAME
U$10: SPARKFUN_LOGO0.2; SFE_LOGO_NAME_FLAME_.2
U$12: QMK_LOGO
U$13: MICROMOD-LOGO

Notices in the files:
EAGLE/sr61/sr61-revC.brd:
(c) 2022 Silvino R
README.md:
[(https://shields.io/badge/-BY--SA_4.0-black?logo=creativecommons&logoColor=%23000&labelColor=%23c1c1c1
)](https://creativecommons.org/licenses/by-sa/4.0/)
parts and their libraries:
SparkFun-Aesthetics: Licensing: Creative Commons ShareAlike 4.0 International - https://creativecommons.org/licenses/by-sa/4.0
